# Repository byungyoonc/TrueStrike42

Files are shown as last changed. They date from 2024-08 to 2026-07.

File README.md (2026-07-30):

# TrueStrike42
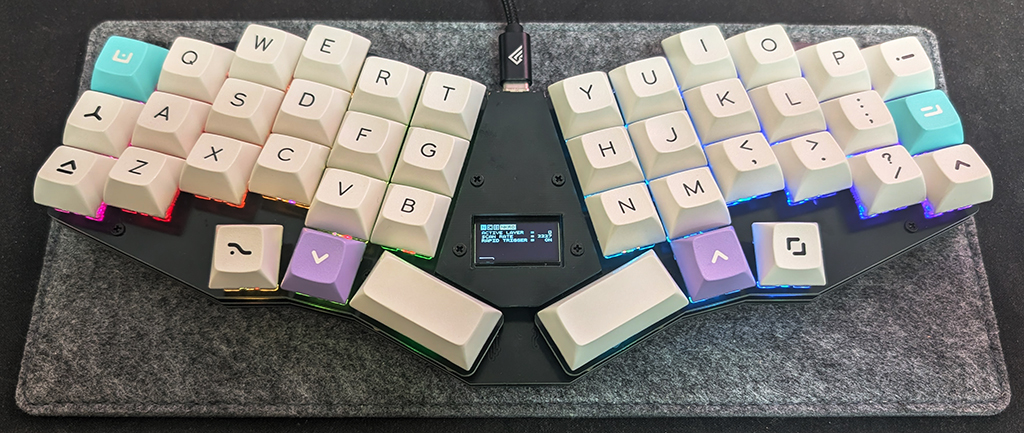
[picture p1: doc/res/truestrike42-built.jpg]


TrueStrike42 is a columnar staggered unibody split Hall-effect keyboard designed to maximize performance[^1] and minimize finger fatigue.

[^1]: specifically on rhythm games

# Layout
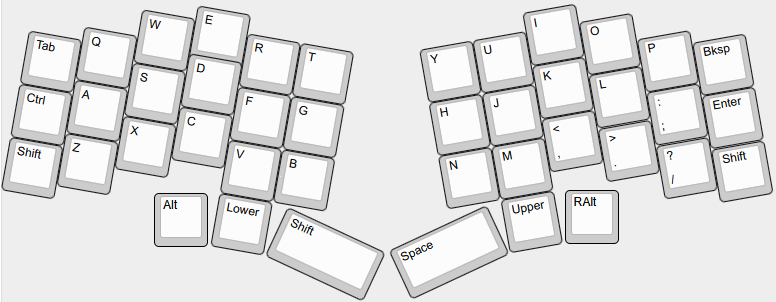
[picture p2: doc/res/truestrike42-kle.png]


# How to build
Refer to the [build guide](doc/buildguide.md) for detailed instructions.

# Firmware
> [!WARNING]
> MCU will behave very erratic (e.g. sending random keypresses rapidly) right after flashing the firmware, before soldering all the components on the board. This is because MCU's analogue pins are connected to nothing, resulting in noise sensor values. 
>
> Disconnect the MCU from the PC as soon as possible after the successful firmware flash to prevent chaos.
> 
## Use Precompiled Binary
Flash `fw/truestrike42_via.uf2` to your RP2040 microcontroller in bootloader mode.

## Build on Your Own
### Option A
Copy the `fw/truestrike42` folder into your cloned QMK Firmware repository's `keyboards` folder, then run `qmk compile -kb truestrike42 -km via`.

### Option B
- [QMK Firmware fork](https://github.com/byungyoonc/qmk_firmware/tree/Truestrike42)
- [VIA QMK Userspace fork](https://github.com/byungyoonc/qmk_userspace_via/tree/truestrike42)

The branches above are from my fork of the QMK Firmware/Userspace repository which supports firmware compilation for TrueStrike42. 

Follow [this guide for External QMK Userspace](https://docs.qmk.fm/newbs_external_userspace) to build it yourself.

# Using VIA HE Configurations
You can access the following tools in VIA by selecting **HE TOOLS** in the menu next to **LIGHTING**.

## Load VIA Definition
Open `fw/truestrike42.json` in VIA's **DESIGN** tab to enable VIA support for TrueStrike42.

## Calibrations
**Make sure to run the calibration at least once before using the keyboard!**
### Bottoming Calibration
Calibrates Hall-effect sensor values for each switch when it is fully bottomed out.

Toggle on, fully bottom out each switch, then toggle off.

### Noise Floor Calibration
Calibrates the ambient magnetic flux fluctuation detected by the Hall-effect sensors.

Click once while leaving the keyboard untouched for a brief period. The firmware samples the noise baseline.

### Show Calibration Data
Prints out current calibration data to the debug console.

### Clear Bottoming Calibration Data
Resets Bottoming Calibration Data to prepare for recalibration. Use this when replacing your Hall-effect switches.

## Actuation
### Mode
Choose between APC and Rapid Trigger.

APC works like a traditional digital switch, but you can change where actuation/release occurs.

Rapid Trigger tracks the switch's height to determine whether the key is being pressed down or released.

### Offsets
Sets the offset values for the selected Mode.

The value ranges from 1 (Topmost) to 255 (Bottommost).

# Related Projects

- [Cipulot's EC Boards](https://github.com/qmk/qmk_firmware/tree/master/keyboards/cipulot/common)
  - TrueStrike42's QMK firmware code for analog signal processing was heavily based on the code for the Cipulot's EC boards.
- [Boardloaf HE](https://github.com/Hanthebot/Boardloaf-HE)
  - 36 key HE split keyboard project by Hanthebot. Their schematics design was derived from TrueStrike42.

# Copyright Notice
`True-Strike-icon.kicad_mod` was created by modifying an icon image for True Strike in the game Baldur's Gate 3, a game by Larian Studios. I used it in accordance with the [Larian Fan Content Policy](https://larian.com/fan-content-policy).

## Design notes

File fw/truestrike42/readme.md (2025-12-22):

# TrueStrike42

truestrike42

TrueStrike42 is a columnar staggered unibody split Hall effect keyboard designed to maximize performance and minimize finger fatigue.

Hall effect part of this firmware code is a derivative work of Cipulot's code.
OLED display part of this firmware code is a derivative work of Dasky's code.

* Keyboard Maintainer: [byungyoonc](https://github.com/byungyoonc)
* Hardware Supported: RP2040 development boards with Pro Micro pin layout
* Hardware Availability: https://github.com/byungyoonc/TrueStrike42

Make example for this keyboard (after setting up your build environment):

    make truestrike42:default

Flashing example for this keyboard:

    make truestrike42:default:flash
    
    OR
    
    Copy the built `uf2` firmware file into `RPI-RP2` drive when the controller is in the bootloader mode

See the [build environment setup](https://docs.qmk.fm/#/getting_started_build_tools) and the [make instructions](https://docs.qmk.fm/#/getting_started_make_guide) for more information. Brand new to QMK? Start with our [Complete Newbs Guide](https://docs.qmk.fm/#/newbs).

## Bootloader

Enter the bootloader in 2 ways:

* **Physical reset button**: Quickly double-press the button on the back of the PCB
* **Keycode in layout**: Press the key mapped to `QK_BOOT` if it is available

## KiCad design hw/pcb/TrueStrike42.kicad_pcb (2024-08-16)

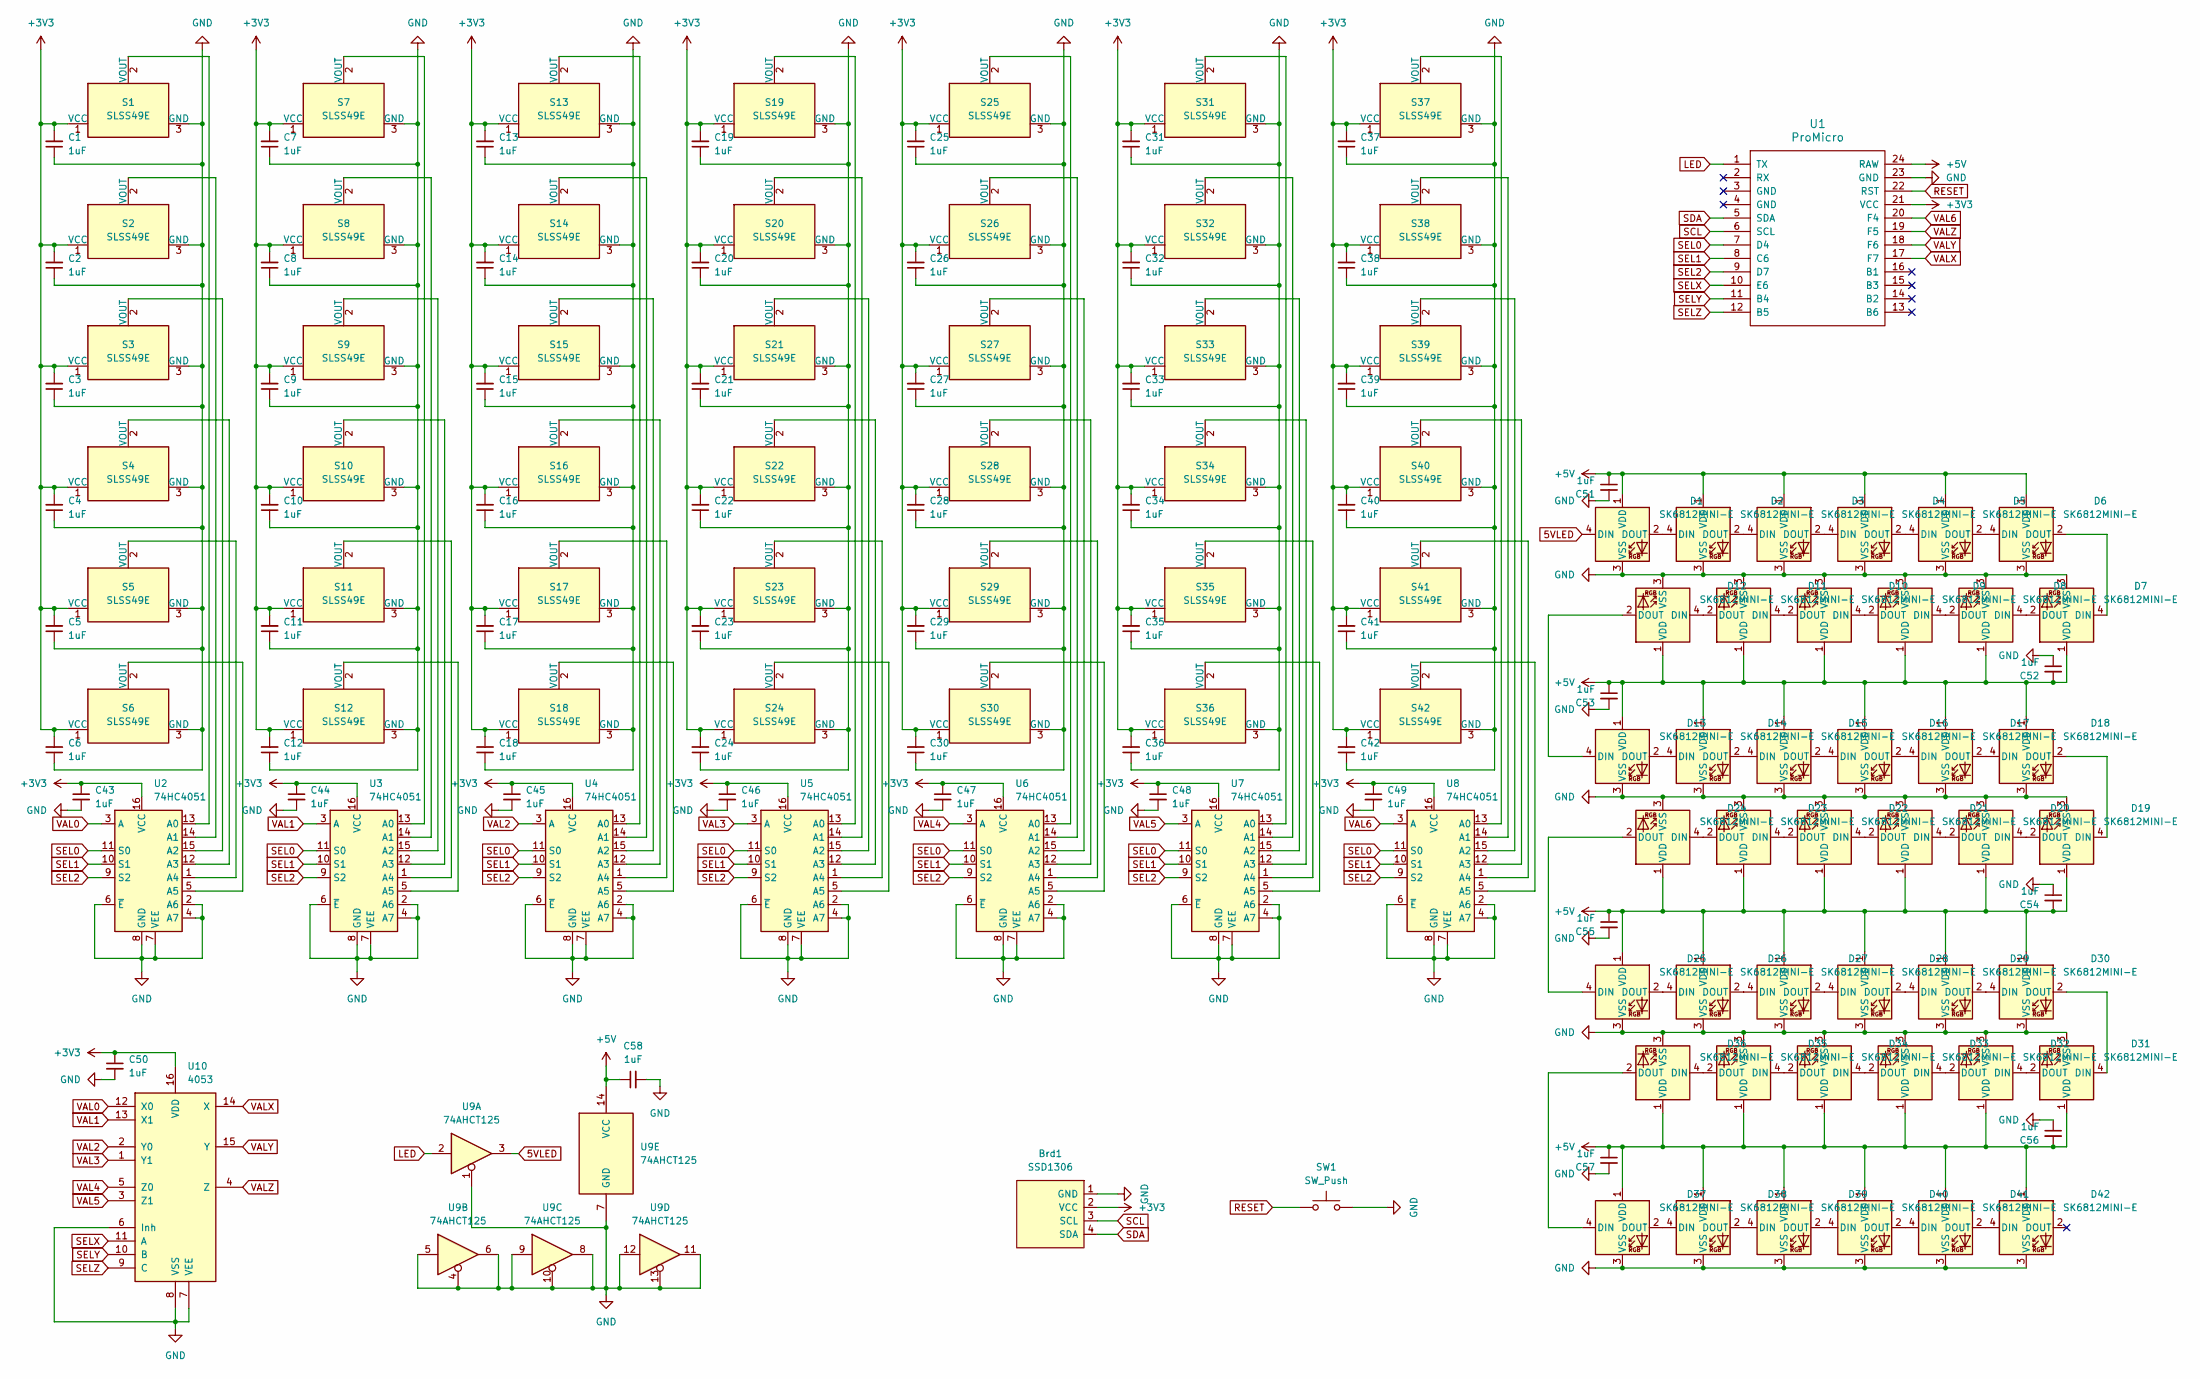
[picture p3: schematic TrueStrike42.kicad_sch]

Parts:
Brd1: SSD1306; 128x64OLED
C1, C2, C3, C4, C5, C6, C7, C8, C9, C10, C11, C12, C13, C14, C15, C16, C17, C18, C19, C20, C21, C22, C23, C24, C25, C26, C27, C28, C29, C30, C31, C32, C33, C34, C35, C36, C37, C38, C39, C40, C41, C42, C43, C44, C45, C46, C47, C48, C49, C50, C51, C52, C53, C54, C55, C56, C57, C58: 1uF; C_0805_2012Metric_Pad1.18x1.45mm_HandSolder
D1, D2, D3, D4, D5, D6, D13, D14, D15, D16, D17, D18, D25, D26, D27, D28, D29, D30, D37, D38, D39, D40, D41, D42: SK6812MINI-E; SK6812MINI-E_nusumi
D7, D8, D9, D10, D11, D12, D19, D20, D21, D22, D23, D24, D31, D32, D33, D34, D35, D36: SK6812MINI-E; SK6812MINI-E_nusumi_Rotated
S1, S2, S3, S4, S5, S6, S7, S8, S9, S10, S11, S12, S13, S14, S15, S16, S17, S18, S19, S20, S21, S22, S23, S24, S25, S26, S27, S28, S29, S30, S31, S32, S33, S34, S35, S36, S37, S38, S41, S42: SLSS49E; HE-Switch-1U
S39, S40: SLSS49E; HE-Switch-2U
SW1: SW_Push; SW_Tactile_SPST_NO_Straight_CK_PTS636Sx25SMTRLFS
U1: ProMicro
U2, U3, U4, U5, U6, U7, U8: 74HC4051; SOIC-16_3.9x9.9mm_P1.27mm
U9: 74AHCT125; SOIC-14_3.9x8.7mm_P1.27mm
U10: 4053; SOIC-16_3.9x9.9mm_P1.27mm

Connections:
5VLED: D1.4 (DIN), U9.3
+3V3: Brd1.2 (VCC), C1.2, C2.2, C3.2, C4.2, C5.2, C6.2, C7.2, C8.2, C9.2, C10.2, C11.2, C12.2, C13.2, C14.2, C15.2, C16.2, C17.2, C18.2, C19.2, C20.2, C21.2, C22.2, C23.2, C24.2, C25.2, C26.2, C27.2, C28.2, C29.2, C30.2, C31.2, C32.2, C33.2, C34.2, C35.2, C36.2, C37.2, C38.2, C39.2, C40.2, C41.2, C42.2, C43.1, C44.1, C45.1, C46.1, C47.1, C48.1, C49.1, C50.1, S1.1 (VCC), S2.1 (VCC), S3.1 (VCC), S4.1 (VCC), S5.1 (VCC), S6.1 (VCC), S7.1 (VCC), S8.1 (VCC), S9.1 (VCC), S10.1 (VCC), S11.1 (VCC), S12.1 (VCC), S13.1 (VCC), S14.1 (VCC), S15.1 (VCC), S16.1 (VCC), S17.1 (VCC), S18.1 (VCC), S19.1 (VCC), S20.1 (VCC), S21.1 (VCC), S22.1 (VCC), S23.1 (VCC), S24.1 (VCC), S25.1 (VCC), S26.1 (VCC), S27.1 (VCC), S28.1 (VCC), S29.1 (VCC), S30.1 (VCC), S31.1 (VCC), S32.1 (VCC), S33.1 (VCC), S34.1 (VCC), S35.1 (VCC), S36.1 (VCC), S37.1 (VCC), S38.1 (VCC), S39.1 (VCC), S40.1 (VCC), S41.1 (VCC), S42.1 (VCC), U1.21 (VCC), U2.16 (VCC), U3.16 (VCC), U4.16 (VCC), U5.16 (VCC), U6.16 (VCC), U7.16 (VCC), U8.16 (VCC), U10.16 (VDD)
+5V: C51.1, C52.2, C53.1, C54.2, C55.1, C56.2, C57.1, C58.1, D1.1 (VDD), D2.1 (VDD), D3.1 (VDD), D4.1 (VDD), D5.1 (VDD), D6.1 (VDD), D7.1 (VDD), D8.1 (VDD), D9.1 (VDD), D10.1 (VDD), D11.1 (VDD), D12.1 (VDD), D13.1 (VDD), D14.1 (VDD), D15.1 (VDD), D16.1 (VDD), D17.1 (VDD), D18.1 (VDD), D19.1 (VDD), D20.1 (VDD), D21.1 (VDD), D22.1 (VDD), D23.1 (VDD), D24.1 (VDD), D25.1 (VDD), D26.1 (VDD), D27.1 (VDD), D28.1 (VDD), D29.1 (VDD), D30.1 (VDD), D31.1 (VDD), D32.1 (VDD), D33.1 (VDD), D34.1 (VDD), D35.1 (VDD), D36.1 (VDD), D37.1 (VDD), D38.1 (VDD), D39.1 (VDD), D40.1 (VDD), D41.1 (VDD), D42.1 (VDD), U1.24 (RAW), U9.14 (VCC)
GND: Brd1.1 (GND), C1.1, C2.1, C3.1, C4.1, C5.1, C6.1, C7.1, C8.1, C9.1, C10.1, C11.1, C12.1, C13.1, C14.1, C15.1, C16.1, C17.1, C18.1, C19.1, C20.1, C21.1, C22.1, C23.1, C24.1, C25.1, C26.1, C27.1, C28.1, C29.1, C30.1, C31.1, C32.1, C33.1, C34.1, C35.1, C36.1, C37.1, C38.1, C39.1, C40.1, C41.1, C42.1, C43.2, C44.2, C45.2, C46.2, C47.2, C48.2, C49.2, C50.2, C51.2, C52.1, C53.2, C54.1, C55.2, C56.1, C57.2, C58.2, D1.3 (VSS), D2.3 (VSS), D3.3 (VSS), D4.3 (VSS), D5.3 (VSS), D6.3 (VSS), D7.3 (VSS), D8.3 (VSS), D9.3 (VSS), D10.3 (VSS), D11.3 (VSS), D12.3 (VSS), D13.3 (VSS), D14.3 (VSS), D15.3 (VSS), D16.3 (VSS), D17.3 (VSS), D18.3 (VSS), D19.3 (VSS), D20.3 (VSS), D21.3 (VSS), D22.3 (VSS), D23.3 (VSS), D24.3 (VSS), D25.3 (VSS), D26.3 (VSS), D27.3 (VSS), D28.3 (VSS), D29.3 (VSS), D30.3 (VSS), D31.3 (VSS), D32.3 (VSS), D33.3 (VSS), D34.3 (VSS), D35.3 (VSS), D36.3 (VSS), D37.3 (VSS), D38.3 (VSS), D39.3 (VSS), D40.3 (VSS), D41.3 (VSS), D42.3 (VSS), S1.3 (GND), S2.3 (GND), S3.3 (GND), S4.3 (GND), S5.3 (GND), S6.3 (GND), S7.3 (GND), S8.3 (GND), S9.3 (GND), S10.3 (GND), S11.3 (GND), S12.3 (GND), S13.3 (GND), S14.3 (GND), S15.3 (GND), S16.3 (GND), S17.3 (GND), S18.3 (GND), S19.3 (GND), S20.3 (GND), S21.3 (GND), S22.3 (GND), S23.3 (GND), S24.3 (GND), S25.3 (GND), S26.3 (GND), S27.3 (GND), S28.3 (GND), S29.3 (GND), S30.3 (GND), S31.3 (GND), S32.3 (GND), S33.3 (GND), S34.3 (GND), S35.3 (GND), S36.3 (GND), S37.3 (GND), S38.3 (GND), S39.3 (GND), S40.3 (GND), S41.3 (GND), S42.3 (GND), SW1.2, U1.23 (GND), U2.2 (A6), U2.4 (A7), U2.6 (~E), U2.7 (VEE), U2.8 (GND), U3.2 (A6), U3.4 (A7), U3.6 (~E), U3.7 (VEE), U3.8 (GND), U4.2 (A6), U4.4 (A7), U4.6 (~E), U4.7 (VEE), U4.8 (GND), U5.2 (A6), U5.4 (A7), U5.6 (~E), U5.7 (VEE), U5.8 (GND), U6.2 (A6), U6.4 (A7), U6.6 (~E), U6.7 (VEE), U6.8 (GND), U7.2 (A6), U7.4 (A7), U7.6 (~E), U7.7 (VEE), U7.8 (GND), U8.2 (A6), U8.4 (A7), U8.6 (~E), U8.7 (VEE), U8.8 (GND), U9.1, U9.4, U9.5, U9.6, U9.7 (GND), U9.8, U9.9, U9.10, U9.11, U9.12, U9.13, U10.6 (Inh), U10.7 (VEE), U10.8 (VSS); also elsewhere on the board
LED: U1.1 (TX), U9.2
unnamed: D1.2 (DOUT), D2.4 (DIN)
unnamed: D2.2 (DOUT), D3.4 (DIN)
unnamed: D3.2 (DOUT), D4.4 (DIN)
unnamed: D4.2 (DOUT), D5.4 (DIN)
unnamed: D5.2 (DOUT), D6.4 (DIN)
unnamed: D6.2 (DOUT), D7.4 (DIN)
unnamed: D7.2 (DOUT), D8.4 (DIN)
unnamed: D8.2 (DOUT), D9.4 (DIN)
unnamed: D9.2 (DOUT), D10.4 (DIN)
unnamed: D10.2 (DOUT), D11.4 (DIN)
unnamed: D11.2 (DOUT), D12.4 (DIN)
unnamed: D12.2 (DOUT), D13.4 (DIN)
unnamed: D13.2 (DOUT), D14.4 (DIN)
unnamed: D14.2 (DOUT), D15.4 (DIN)
unnamed: D15.2 (DOUT), D16.4 (DIN)
unnamed: D16.2 (DOUT), D17.4 (DIN)
unnamed: D17.2 (DOUT), D18.4 (DIN)
unnamed: D18.2 (DOUT), D19.4 (DIN)
unnamed: D19.2 (DOUT), D20.4 (DIN)
unnamed: D20.2 (DOUT), D21.4 (DIN)
unnamed: D21.2 (DOUT), D22.4 (DIN)
unnamed: D22.2 (DOUT), D23.4 (DIN)
unnamed: D23.2 (DOUT), D24.4 (DIN)
unnamed: D24.2 (DOUT), D25.4 (DIN)
unnamed: D25.2 (DOUT), D26.4 (DIN)
unnamed: D26.2 (DOUT), D27.4 (DIN)
unnamed: D27.2 (DOUT), D28.4 (DIN)
unnamed: D28.2 (DOUT), D29.4 (DIN)
unnamed: D29.2 (DOUT), D30.4 (DIN)
unnamed: D30.2 (DOUT), D31.4 (DIN)
unnamed: D31.2 (DOUT), D32.4 (DIN)
unnamed: D32.2 (DOUT), D33.4 (DIN)
unnamed: D33.2 (DOUT), D34.4 (DIN)
unnamed: D34.2 (DOUT), D35.4 (DIN)
unnamed: D35.2 (DOUT), D36.4 (DIN)
unnamed: D36.2 (DOUT), D37.4 (DIN)
unnamed: D37.2 (DOUT), D38.4 (DIN)
unnamed: D38.2 (DOUT), D39.4 (DIN)
unnamed: D39.2 (DOUT), D40.4 (DIN)
unnamed: D40.2 (DOUT), D41.4 (DIN)
unnamed: D41.2 (DOUT), D42.4 (DIN)
unnamed: S1.2 (VOUT), U2.13 (A0)
unnamed: S2.2 (VOUT), U2.14 (A1)
unnamed: S3.2 (VOUT), U2.15 (A2)
unnamed: S4.2 (VOUT), U2.12 (A3)
unnamed: S5.2 (VOUT), U2.1 (A4)
unnamed: S6.2 (VOUT), U2.5 (A5)
unnamed: S7.2 (VOUT), U3.13 (A0)
unnamed: S8.2 (VOUT), U3.14 (A1)
unnamed: S9.2 (VOUT), U3.15 (A2)
unnamed: S10.2 (VOUT), U3.12 (A3)
unnamed: S11.2 (VOUT), U3.1 (A4)
unnamed: S12.2 (VOUT), U3.5 (A5)
unnamed: S13.2 (VOUT), U4.13 (A0)
unnamed: S14.2 (VOUT), U4.14 (A1)
unnamed: S15.2 (VOUT), U4.15 (A2)
unnamed: S16.2 (VOUT), U4.12 (A3)
unnamed: S17.2 (VOUT), U4.1 (A4)
unnamed: S18.2 (VOUT), U4.5 (A5)
unnamed: S19.2 (VOUT), U5.13 (A0)
unnamed: S20.2 (VOUT), U5.14 (A1)
unnamed: S21.2 (VOUT), U5.15 (A2)
unnamed: S22.2 (VOUT), U5.12 (A3)
unnamed: S23.2 (VOUT), U5.1 (A4)
unnamed: S24.2 (VOUT), U5.5 (A5)
unnamed: S25.2 (VOUT), U6.13 (A0)
unnamed: S26.2 (VOUT), U6.14 (A1)
unnamed: S27.2 (VOUT), U6.15 (A2)
unnamed: S28.2 (VOUT), U6.12 (A3)
unnamed: S29.2 (VOUT), U6.1 (A4)
unnamed: S30.2 (VOUT), U6.5 (A5)
unnamed: S31.2 (VOUT), U7.13 (A0)
unnamed: S32.2 (VOUT), U7.14 (A1)
unnamed: S33.2 (VOUT), U7.15 (A2)
unnamed: S34.2 (VOUT), U7.12 (A3)
unnamed: S35.2 (VOUT), U7.1 (A4)
unnamed: S36.2 (VOUT), U7.5 (A5)
unnamed: S37.2 (VOUT), U8.13 (A0)
unnamed: S38.2 (VOUT), U8.14 (A1)
unnamed: S39.2 (VOUT), U8.15 (A2)
unnamed: S40.2 (VOUT), U8.12 (A3)
unnamed: S41.2 (VOUT), U8.1 (A4)
unnamed: S42.2 (VOUT), U8.5 (A5)
RESET: SW1.1, U1.22 (RST); also elsewhere on the board
SCL: Brd1.3 (SCL), U1.6 (SCL)
SDA: Brd1.4 (SDA), U1.5 (SDA)
SEL0: U1.7 (D4), U2.11 (S0), U3.11 (S0), U4.11 (S0), U5.11 (S0), U6.11 (S0), U7.11 (S0), U8.11 (S0)
SEL1: U1.8 (C6), U2.10 (S1), U3.10 (S1), U4.10 (S1), U5.10 (S1), U6.10 (S1), U7.10 (S1), U8.10 (S1)
SEL2: U1.9 (D7), U2.9 (S2), U3.9 (S2), U4.9 (S2), U5.9 (S2), U6.9 (S2), U7.9 (S2), U8.9 (S2)
SELX: U1.10 (E6), U10.11 (A)
SELY: U1.11 (B4), U10.10 (B)
SELZ: U1.12 (B5), U10.9 (C)
VAL0: U2.3 (A), U10.12 (X0)
VAL1: U3.3 (A), U10.13 (X1)
VAL2: U4.3 (A), U10.2 (Y0)
VAL3: U5.3 (A), U10.1 (Y1)
VAL4: U6.3 (A), U10.5 (Z0)
VAL5: U7.3 (A), U10.3 (Z1)
VAL6: U1.20 (F4), U8.3 (A)
VALX: U1.17 (F7), U10.14 (X)
VALY: U1.18 (F6), U10.15 (Y)
VALZ: U1.19 (F5), U10.4 (Z)

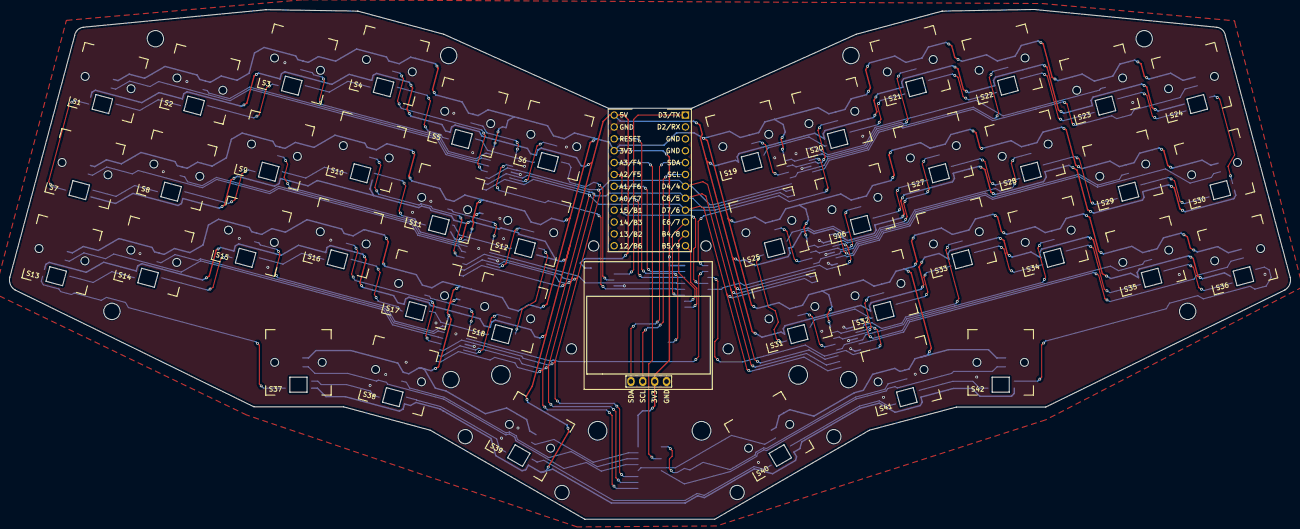
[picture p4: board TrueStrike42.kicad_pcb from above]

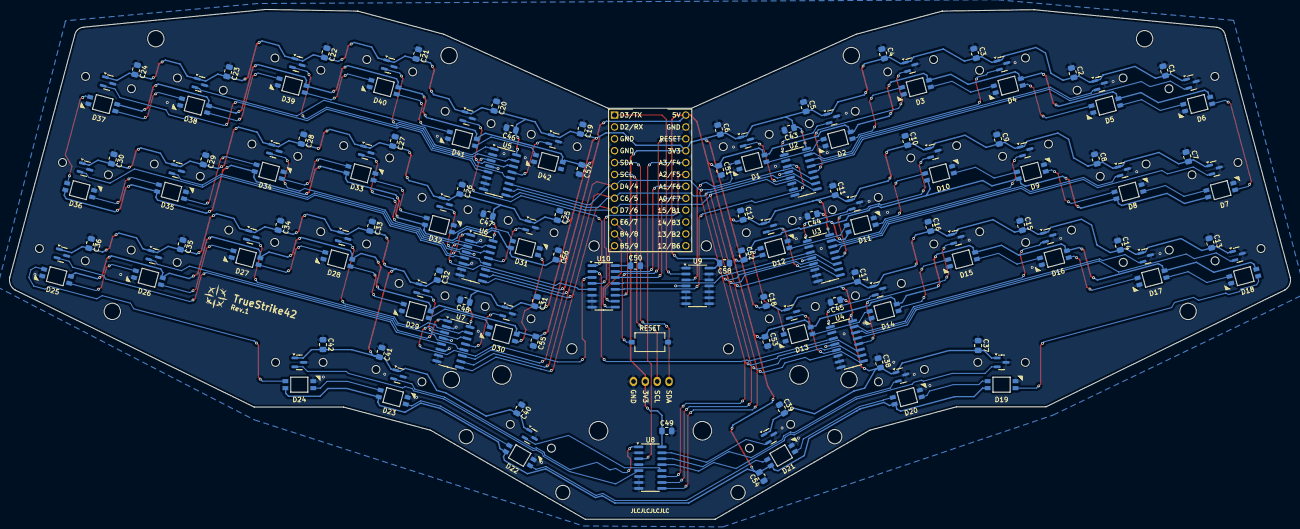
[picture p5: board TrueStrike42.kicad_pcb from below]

Board: 2 copper layers, 273.9 x 109.0 mm, 154 parts (111 on the bottom side), 107 nets.

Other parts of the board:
RESET: SW_Push; SW_Tactile_SPST_NO_Straight_CK_PTS636Sx25SMTRLFS

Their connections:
GND: RESET.2; also elsewhere on the board
RESET: RESET.1; also elsewhere on the board

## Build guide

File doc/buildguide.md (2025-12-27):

# Build Guide for TrueStrike42
## BOM (Bill of Material)
### Required
| Name | Count | Notes |
| ---- | ----- | --- |
| Main board PCB | x1 | |
| MCU Cover | x1 | |
| Bottom Plate | x1 | |
| Top Plate | x2 | Use one for each side, one of them flipped |
| Hall-effect sensor in SOT-23-3 package | x42 | e.g. SLSS49e, GH39FKSW |
| 0.1uF~1uF Capacitors in 0805 SMD package | x58 | e.g. CL21B124KAC |
| 74HC4051 in SOIC-16 package | x7 | 8-channel analog multiplexer |
| 4053 in SOIC-16 package | x1 | Triple 2-channel analog multiplexer |
| 74AHCT125 in SOIC-14 package | x1 | 3V-5V level shifter |
| SMD Tact Switch (6.0x3.5mm) | x1 | Reset button |
| RP2040 dev board with ProMicro compatible pinouts | x1 | Uses A0 through A3 as analog input pins |
| M2 4mm bolts | x24 | Preferably flat-headed |
| M2 7~8mm standoff | x12 | You might need longer ones for the MCU cover, depending on what pin sockets/headers you're using |

### Optional
| Name | Count | Notes |
| ---- | ----- | --- |
| 128x64 OLED Screen | x1 | e.g. SSD1306 |
| SK6812MINI-E | x42 | Per-key RGB Matrix |
| MCU Pin Sockets | x2 (12pins) | Makes MCU to be detached easier when things go south |
| MCU Pin Headers | x2 (12pins) | Can be replaced with through-hole diode legs |

### Not Included in CAD, Required for the Use
| Name | Count | Notes |
| ---- | ----- | --- |
| N-pole bottom magnetic keyboard switches | x42 | Any Wooting-compatible switches will work |
| Keycaps | x42 | Ones that fit your switches, likely MX stem compatible |
| Bumpons | x4~8 | Small bumpons with adhesive will do |
| 2u stabilizers | x2 | (Optional) |
| USB-C cable | x1 | |

## Soldering Components
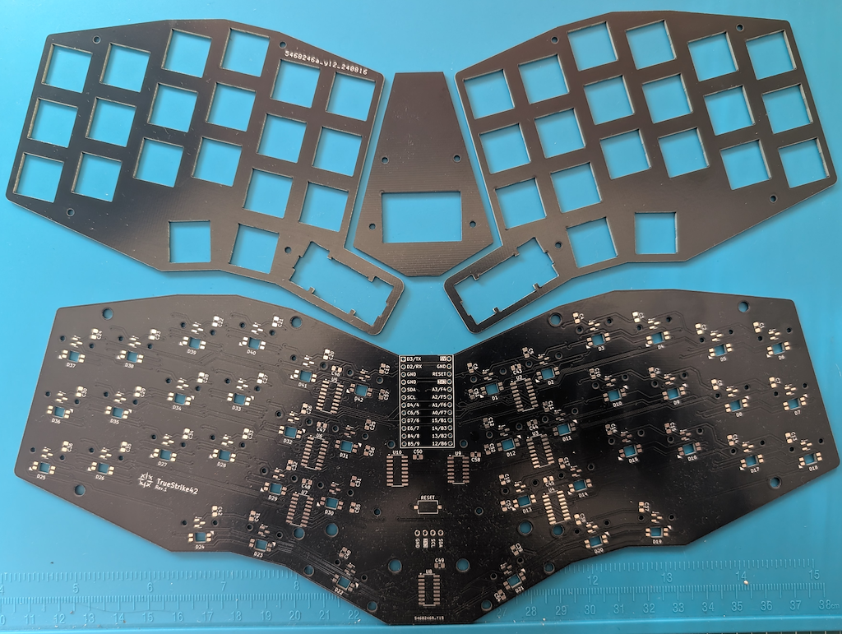
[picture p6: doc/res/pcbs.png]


Get your PCB and plates ready, and solder the components on the PCB.

> [!NOTE]
> MCU's bootloader mode buttons can be very hard to access after all the soldering, so consider flashing the firmware beforehand.

> [!WARNING]
> MCU will behave very erratic (e.g. sending random keypresses rapidly) right after flashing the firmware, before soldering all the components on the board. This is because MCU's analogue pins are connected to nothing, resulting in noise sensor values. 
>
> Disconnect the MCU from the PC as soon as possible after the successful firmware flash to prevent chaos.

After the soldering, back of the PCB will look like this:

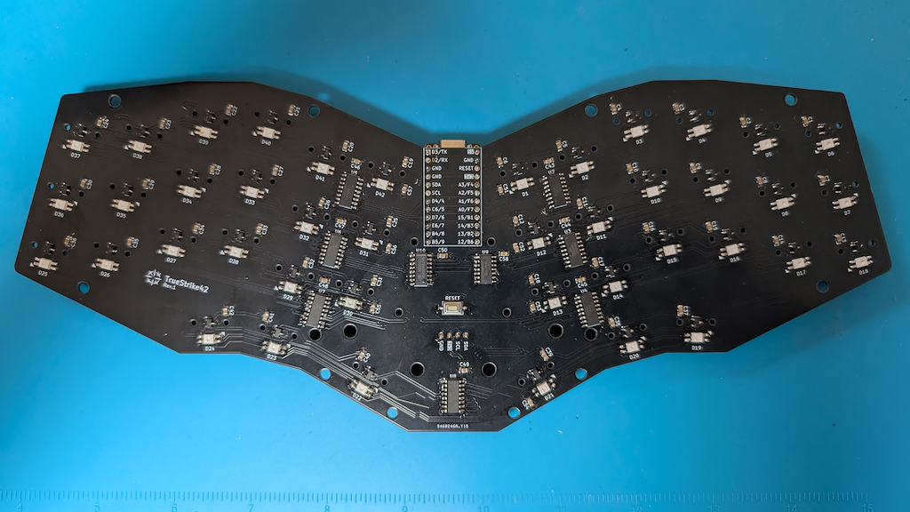
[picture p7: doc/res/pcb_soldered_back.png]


> [!NOTE]
> While soldering the components, make sure you're soldering the right component to the right position. Especially those ICs with SOIC packages can be tricky to identify; 
>
> - U2 through U8 uses 74HC4501
> - U9 uses 74AHCT125
> - U10 uses 4503.

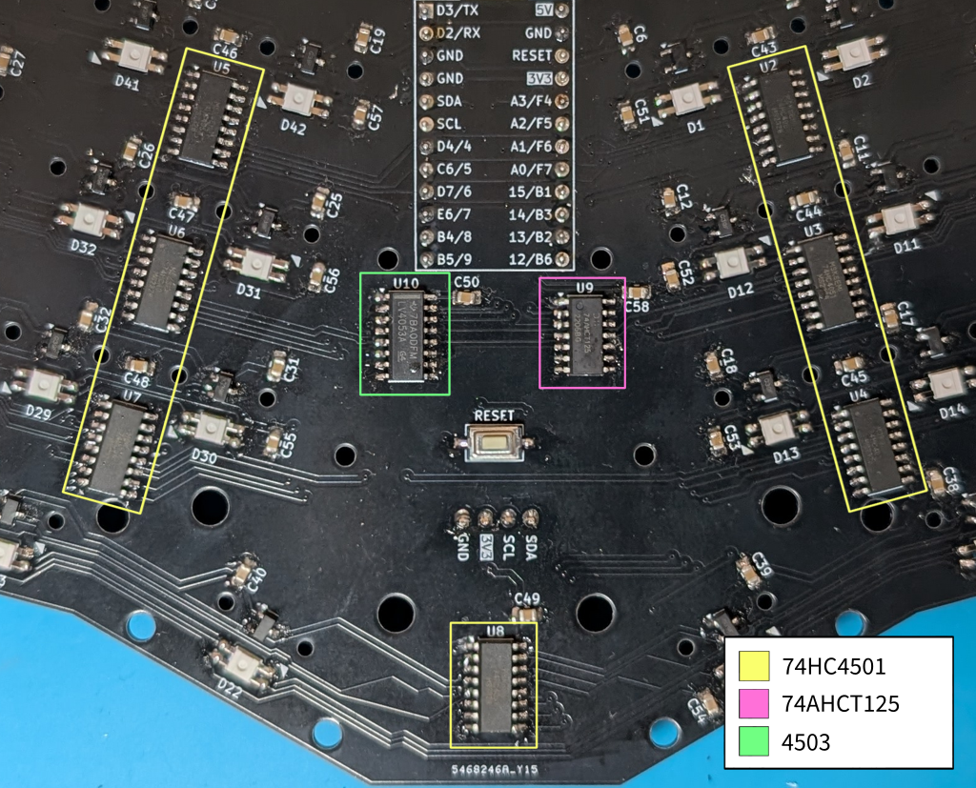
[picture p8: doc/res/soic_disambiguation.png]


## Assembly

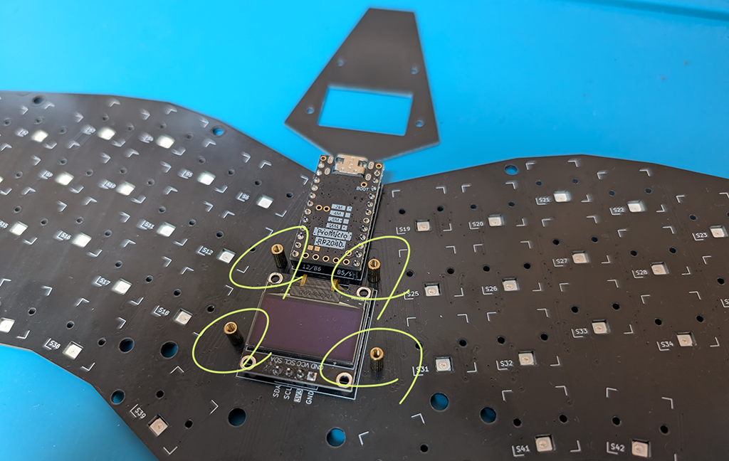
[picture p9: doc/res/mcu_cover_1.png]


Lock 4 standoffs in their place on the PCB first, 

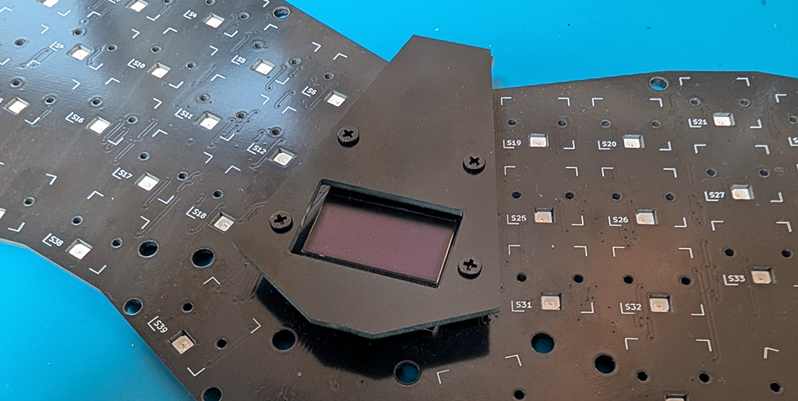
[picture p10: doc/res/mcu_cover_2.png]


Then assemble the MCU cover.

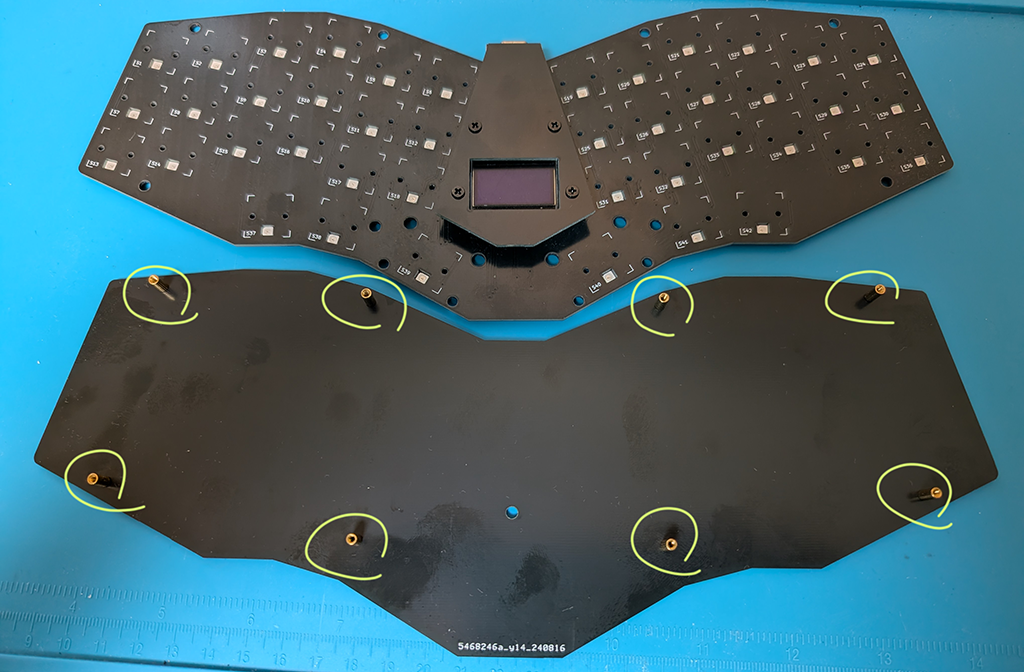
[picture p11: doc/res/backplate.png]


Same with the bottom plate. Lock 8 standoffs in their place first,

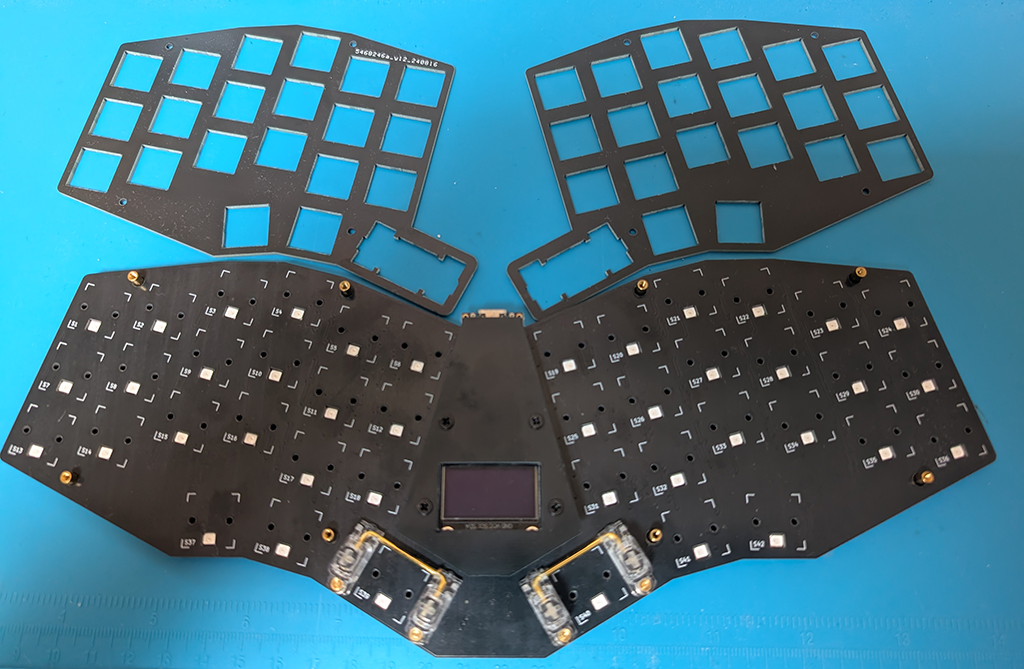
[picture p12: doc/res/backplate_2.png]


Put the PCB on top of the bottom plate, letting the standoffs go through slightly bigger holes punched in the PCB.

If you use stabilizers, install them here.

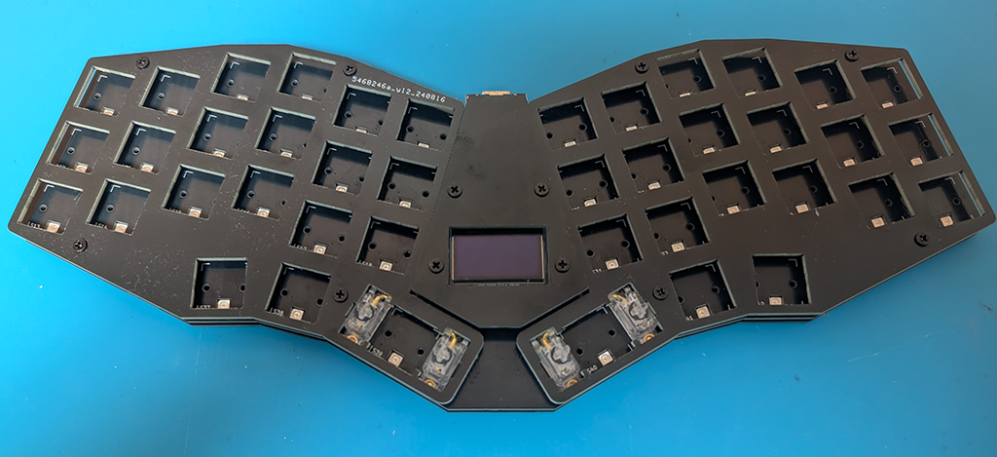
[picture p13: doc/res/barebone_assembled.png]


Assemble two top plates to complete the barebone build.

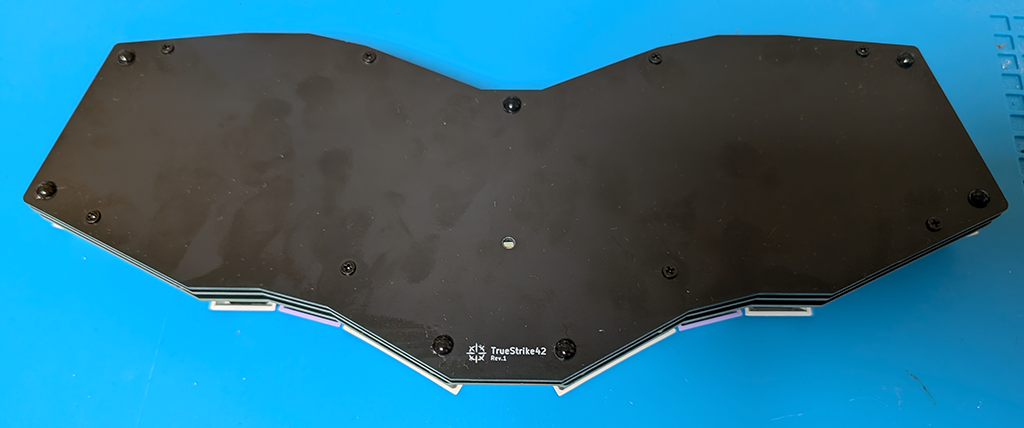
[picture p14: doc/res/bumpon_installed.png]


Flip the board and apply bumpons to prevent the keyboard from slipping around while typing.

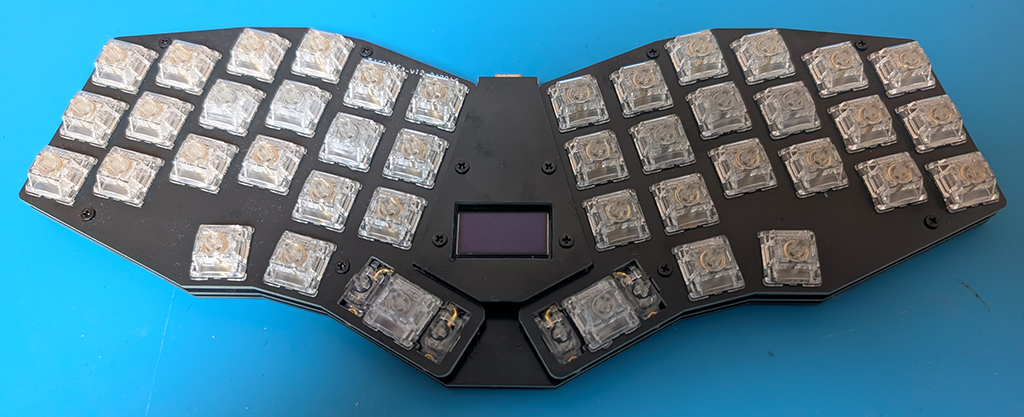
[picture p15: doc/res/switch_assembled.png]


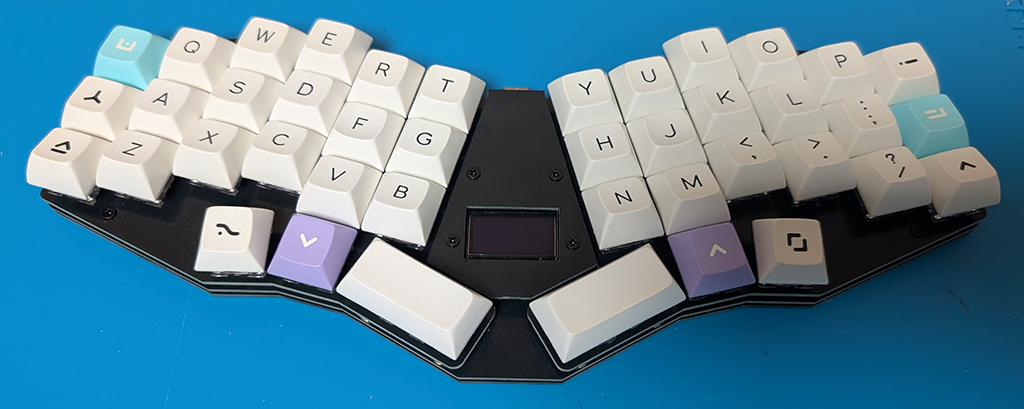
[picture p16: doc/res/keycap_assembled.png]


Install the switches and keycaps of your choice, [flash the firmware](../README.md#firmware), [go through the initial setup in VIA](../README.md#using-via-he-configurations) then enjoy the board!

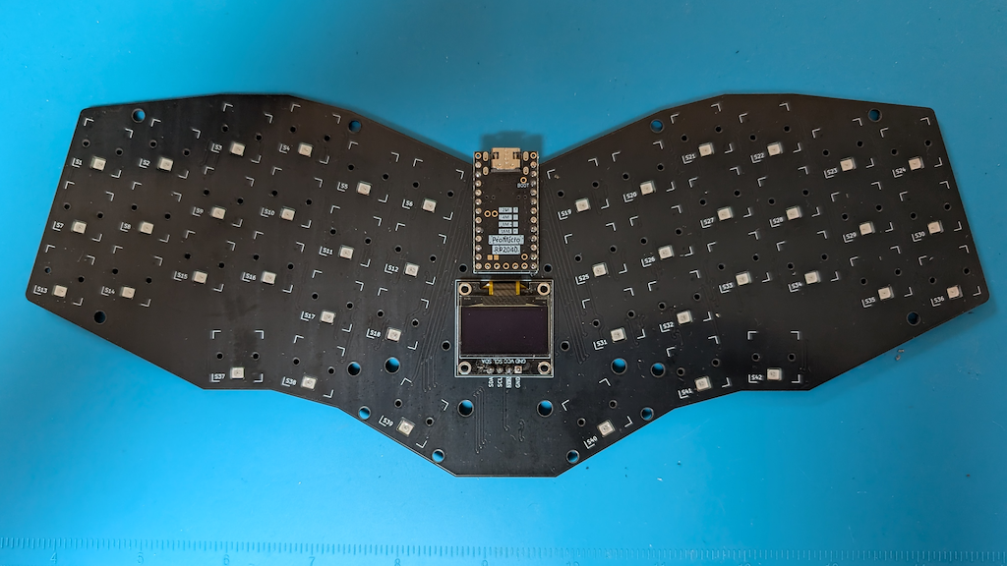
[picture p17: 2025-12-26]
doc/res/pcb_soldered_front.png

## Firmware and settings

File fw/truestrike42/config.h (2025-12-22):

/* Copyright 2024 byungyoonc
 *
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
 * You should have received a copy of the GNU General Public License
 * along with this program.  If not, see <http://www.gnu.org/licenses/>.
 */

#pragma once

#define MATRIX_ROWS 4
#define MATRIX_COLS 12

#define MATRIX_ROW_PINS \
    { GP26, GP27, GP28, GP29 }

#define ROWS_PER_COL \
    { 4, 4, 4, 4, 4, 4, 3, 3, 3, 3, 3, 3 }

#define AMUX_MAX_COLS_COUNT 12

#define AMUX_SEL_PINS \
    { GP4, GP5, GP6, GP7, GP8, GP9 }
#define AMUX_COL_CHANNELS \
    { 0, 1, 2, 3, 4, 5, 56, 57, 58, 59, 60, 61 }

#define DEFAULT_ACTUATION_MODE 0
#define DEFAULT_MODE_0_ACTUATION_LEVEL 350
#define DEFAULT_MODE_0_RELEASE_LEVEL 400
#define DEFAULT_MODE_1_INITIAL_DEADZONE_OFFSET DEFAULT_MODE_0_ACTUATION_LEVEL
#define DEFAULT_MODE_1_ACTUATION_OFFSET 70
#define DEFAULT_MODE_1_RELEASE_OFFSET 70
#define DEFAULT_EXTREMUM 1023
#define NOISE_CEILING_THRESHOLD 50
#define BOTTOMING_CALIBRATION_THRESHOLD 50
#define DEFAULT_NOISE_CEILING_SAMPLING_COUNT 30
#define DEFAULT_BOTTOMING_READING 0
#define DEFAULT_CALIBRATION_STARTER true

#define EECONFIG_KB_DATA_SIZE 105

#define DEBUG_MATRIX_SCAN_RATE

#define QUANTUM_PAINTER_DISPLAY_TIMEOUT 0

#define RP2040_BOOTLOADER_DOUBLE_TAP_RESET

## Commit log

2024-06-23 Initialize KiCad project
    [TrueStrike42.kicad_pcb, TrueStrike42.kicad_sch]
2024-06-23 Add submodules for symbols and footprints
2024-06-23 Add symbols/footprints
2024-07-10 Add project specific symbol library
    And a symbol for a Hall effect sensor we will use here
2024-07-10 Add ProMicro symbols and footprint
2024-07-14 Schema v1
    [TrueStrike42.kicad_sch]
2024-07-15 Add footprints for HE switch
2024-07-15 PCB layout v1
    [TrueStrike42.kicad_pcb]
2024-07-16 Add vertical versions of >1u HE switch footprints
2024-07-20 Add a submodule for symbols and footprints
2024-07-21 Update TrueStrike42.kicad_sch
    Add LED matrix schematics
    [TrueStrike42.kicad_sch]
2024-07-26 Add SK6812MINI-E footprints
2024-07-26 Update PCB and schematic
    [TrueStrike42.kicad_pcb, TrueStrike42.kicad_sch]
2024-07-26 Update TrueStrike42.kicad_pcb
    Rotate left/right hand clusters
    [TrueStrike42.kicad_pcb]
2024-07-26 Update TrueStrike42.kicad_pcb
    Finalize board silhouette
    [TrueStrike42.kicad_pcb]
2024-07-26 Update TrueStrike42.kicad_pro
    Add PWR net class
2024-07-27 Update TrueStrike42.kicad_sch
    Remove unnecessary capacitors
    [TrueStrike42.kicad_sch]
2024-07-27 Update TrueStrike42.kicad_pcb
    Tracing work in progress
    [TrueStrike42.kicad_pcb]
2024-08-03 Update TrueStrike42.kicad_pcb
    Wiring wip: right side done
    [TrueStrike42.kicad_pcb]
2024-08-11 Update TrueStrike42.kicad_pcb
    Wiring finished except for GND
    [TrueStrike42.kicad_pcb]
2024-08-12 Update TrueStrike42.kicad_pcb
    Finished routing
    [TrueStrike42.kicad_pcb]
2024-08-12 Add SSD1306 to footprint and symbol libraries
2024-08-12 Add LED screen and a reset switch
    [TrueStrike42.kicad_pcb, TrueStrike42.kicad_sch]
2024-08-12 GND fill + DRC check pass
    [TrueStrike42.kicad_pcb]
2024-08-14 Update functional silkscreens
    [TrueStrike42.kicad_pcb, TrueStrike42.kicad_sch]
2024-08-14 Update TrueStrike42.kicad_pcb
    Add mounting holes
    [TrueStrike42.kicad_pcb]
2024-08-14 Add logo, fixed wrong pinouts for sensors
    [TrueStrike42.kicad_pcb, TrueStrike42.kicad_sch]
2024-08-14 Update reset button label
    [TrueStrike42.kicad_pcb]
2024-08-14 Add order number locator for JLCPCB
    [TrueStrike42.kicad_pcb]
2024-08-14 Update settings for gerber export
    [TrueStrike42.kicad_pcb]
2024-08-14 Generate gerber files
    [TrueStrike42-B_Cu.gbl, TrueStrike42-B_Mask.gbs, TrueStrike42-B_Paste.gbp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]
2024-08-15 Refined mounting hole positions to be symmetric
    [TrueStrike42.kicad_pcb]
2024-08-15 Update TrueStrike42.kicad_pcb
    Make the rest of the PCB to be symmetric
    [TrueStrike42.kicad_pcb]
2024-08-15 Add top plate
    [TrueStrike42-top-plate.kicad_pcb, TrueStrike42-top-plate.kicad_sch]
2024-08-16 Add OLED/MCU cover
    [TrueStrike42-cover.kicad_pcb, TrueStrike42-cover.kicad_sch]
2024-08-16 Add bottom plate
    [TrueStrike42-bottom-plate.kicad_pcb, TrueStrike42-bottom-plate.kicad_sch]
2024-08-16 Update TrueStrike42-top-plate.kicad_pcb
    Change ID location on top plate
    [TrueStrike42-top-plate.kicad_pcb]
2024-08-16 Update TrueStrike42-cover.kicad_pcb
    Add ID location for cover
    [TrueStrike42-cover.kicad_pcb]
2024-08-16 Update Gerber output formats
    [TrueStrike42-cover.kicad_pcb, TrueStrike42-top-plate.kicad_pcb, TrueStrike42.kicad_pcb]
2024-08-16 Update Gerber output format
    [TrueStrike42-bottom-plate.kicad_pcb]
2024-08-16 Add Gerber outputs
    [TrueStrike42-B_Cu.gbl, TrueStrike42-B_Mask.gbs, TrueStrike42-B_Paste.gbp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]
2025-07-20 Add exported Gerber files to .gitignore

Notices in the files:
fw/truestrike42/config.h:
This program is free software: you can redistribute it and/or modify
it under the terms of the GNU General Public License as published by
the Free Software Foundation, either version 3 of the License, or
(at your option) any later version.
